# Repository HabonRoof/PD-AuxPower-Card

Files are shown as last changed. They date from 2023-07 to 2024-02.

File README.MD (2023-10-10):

# Type-C PD Auxiliary power supply
### _Light, small, isolated digial power_
Tiny-Aux is a small protable auxiliary digital power supply for electrical engineer using everyday.
As a power electronic engineer, I'm tired moving heavy linear bench power for only less then 1W power.
So I develop this Tiny-Aux for four different voltage as auxiliary power source.
It sould support USB type-C connector and PD protocol fand four different output voltage, but now can only draw 5V input.
Most importantly, it's isolated from primary and secondary, ground path is no more concerned.
## Appearence
Appearence of Tiny-Aux Tiny-Aux side view
The two ER9.5 transformer provide physical isolation side by side.
There are two output channel provide 3.3V/5V and 12V/24V saperately. Use two switches to set the output voltage of each channel.
The black/yellow wire and ground pin is for debugging.
## Features
- PWM limit protection
- UART real-time power monitoring

## Fearures to be develop
- Over current/ Over voltage protection
- FUSB302B driver library
- EEPROM for power event recording

## Specification
- Input voltage: 5V-24V (USB PD is in development)
- Channel 1 output voltage: 3.3V/ 5V
- Channel 1 output current: 1000 mA
- Channel 2 output voltage: 12V/ 24V
- Channel 2 output current: 500 mA
- Total putput wattage: 2W

## Technical detail
All of the component can be placed or soldered by machine automatically, **but no transformer**.
This project using flyback topology as isolated power, so the transformer is the key component and need to satisfy following charactisic.
The bobbin size used is ER9.5, core material is PC44, diameter of conductor is 0.5 mm.
The transformer need grind air-gap manualy. The distant is about 0.5mm. (Need to be confirm).
For **Channel 1** 3.3V/5V rail, the transformer should have this charactisic:
- Primary inductance: 330uH, roughtly 10 turns
- Secondary inductance: 30uH, roughtly 30 turns
 -Leakage inductance: 10uH

For **Channel 2** 12V/24V rail, the transformer should have this charactisic:
- Primary inductance: 30uH, roughtly 3 turns
- Secondary inductance: 330uH, roughtly 30 turns
- Leakage inductance: 10uH

The **dot point** of transformer is marked on PCB schematic file, **DOUBLE CHECK the polarity**.

The switching frequency is set to 200kHz, using voltage control for stable output voltage.
PID parameter can be tune to best for dynamic load.

## Important Notice
The communication pin (UART, Debug interface) is grounded with primary side of Tiny-Aux module, please DO NOT connect to the output channel incase burn your computer.
Over current protection and over voltage protection is not implement yet!
USB PD ptorocol is not implement yet!

## Known Issue
- PD protocol can not read PDO message.
- 5V transient will go into unstable state when applying 100 mA 1000mA dynamic load.
- TPS62177 EN pin connect to GND (fixed in schematic)

## Contribute
If you want to join the development, please feel free to send me e-mail, and I'll send you the hardware for free.

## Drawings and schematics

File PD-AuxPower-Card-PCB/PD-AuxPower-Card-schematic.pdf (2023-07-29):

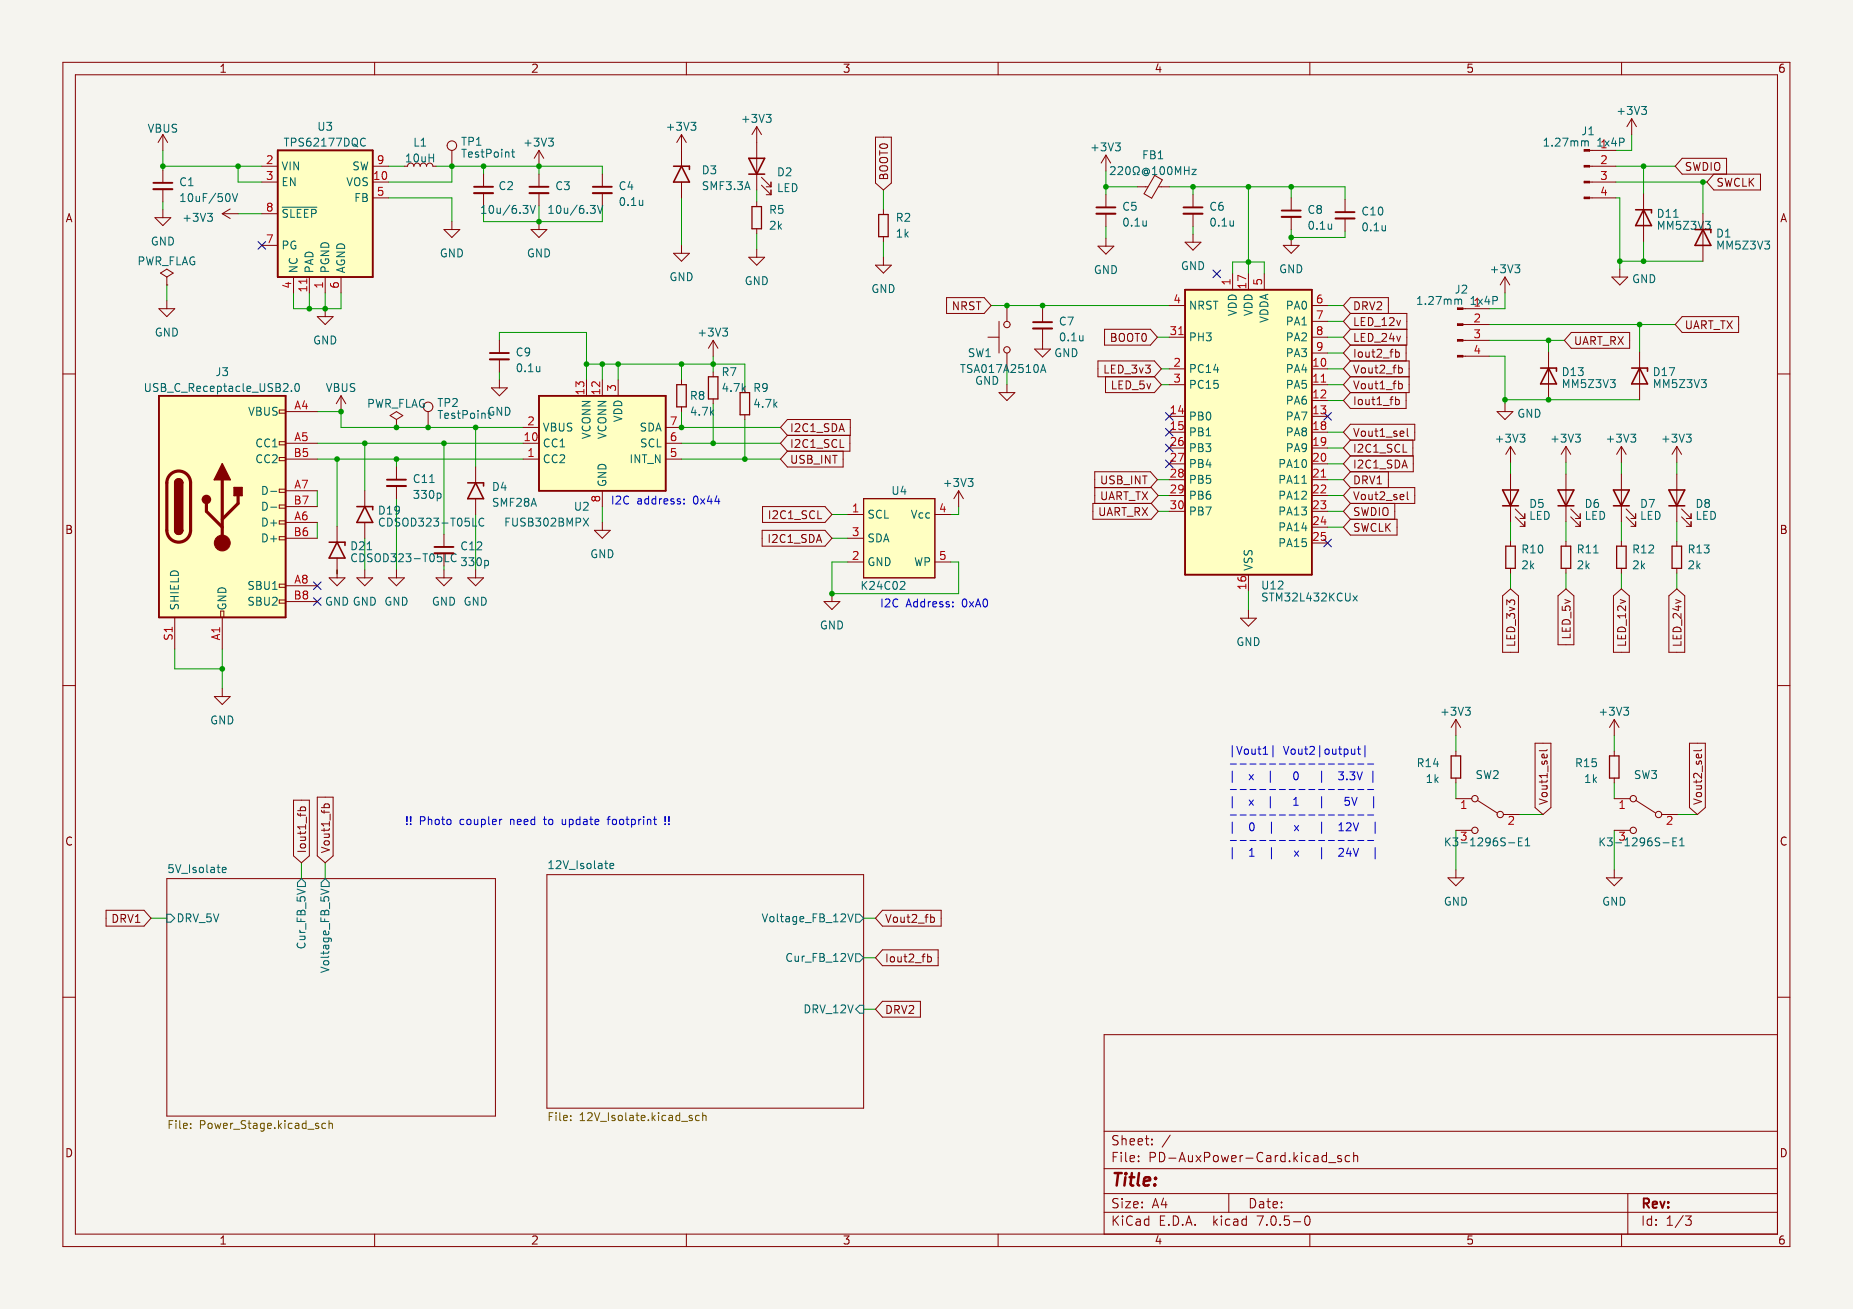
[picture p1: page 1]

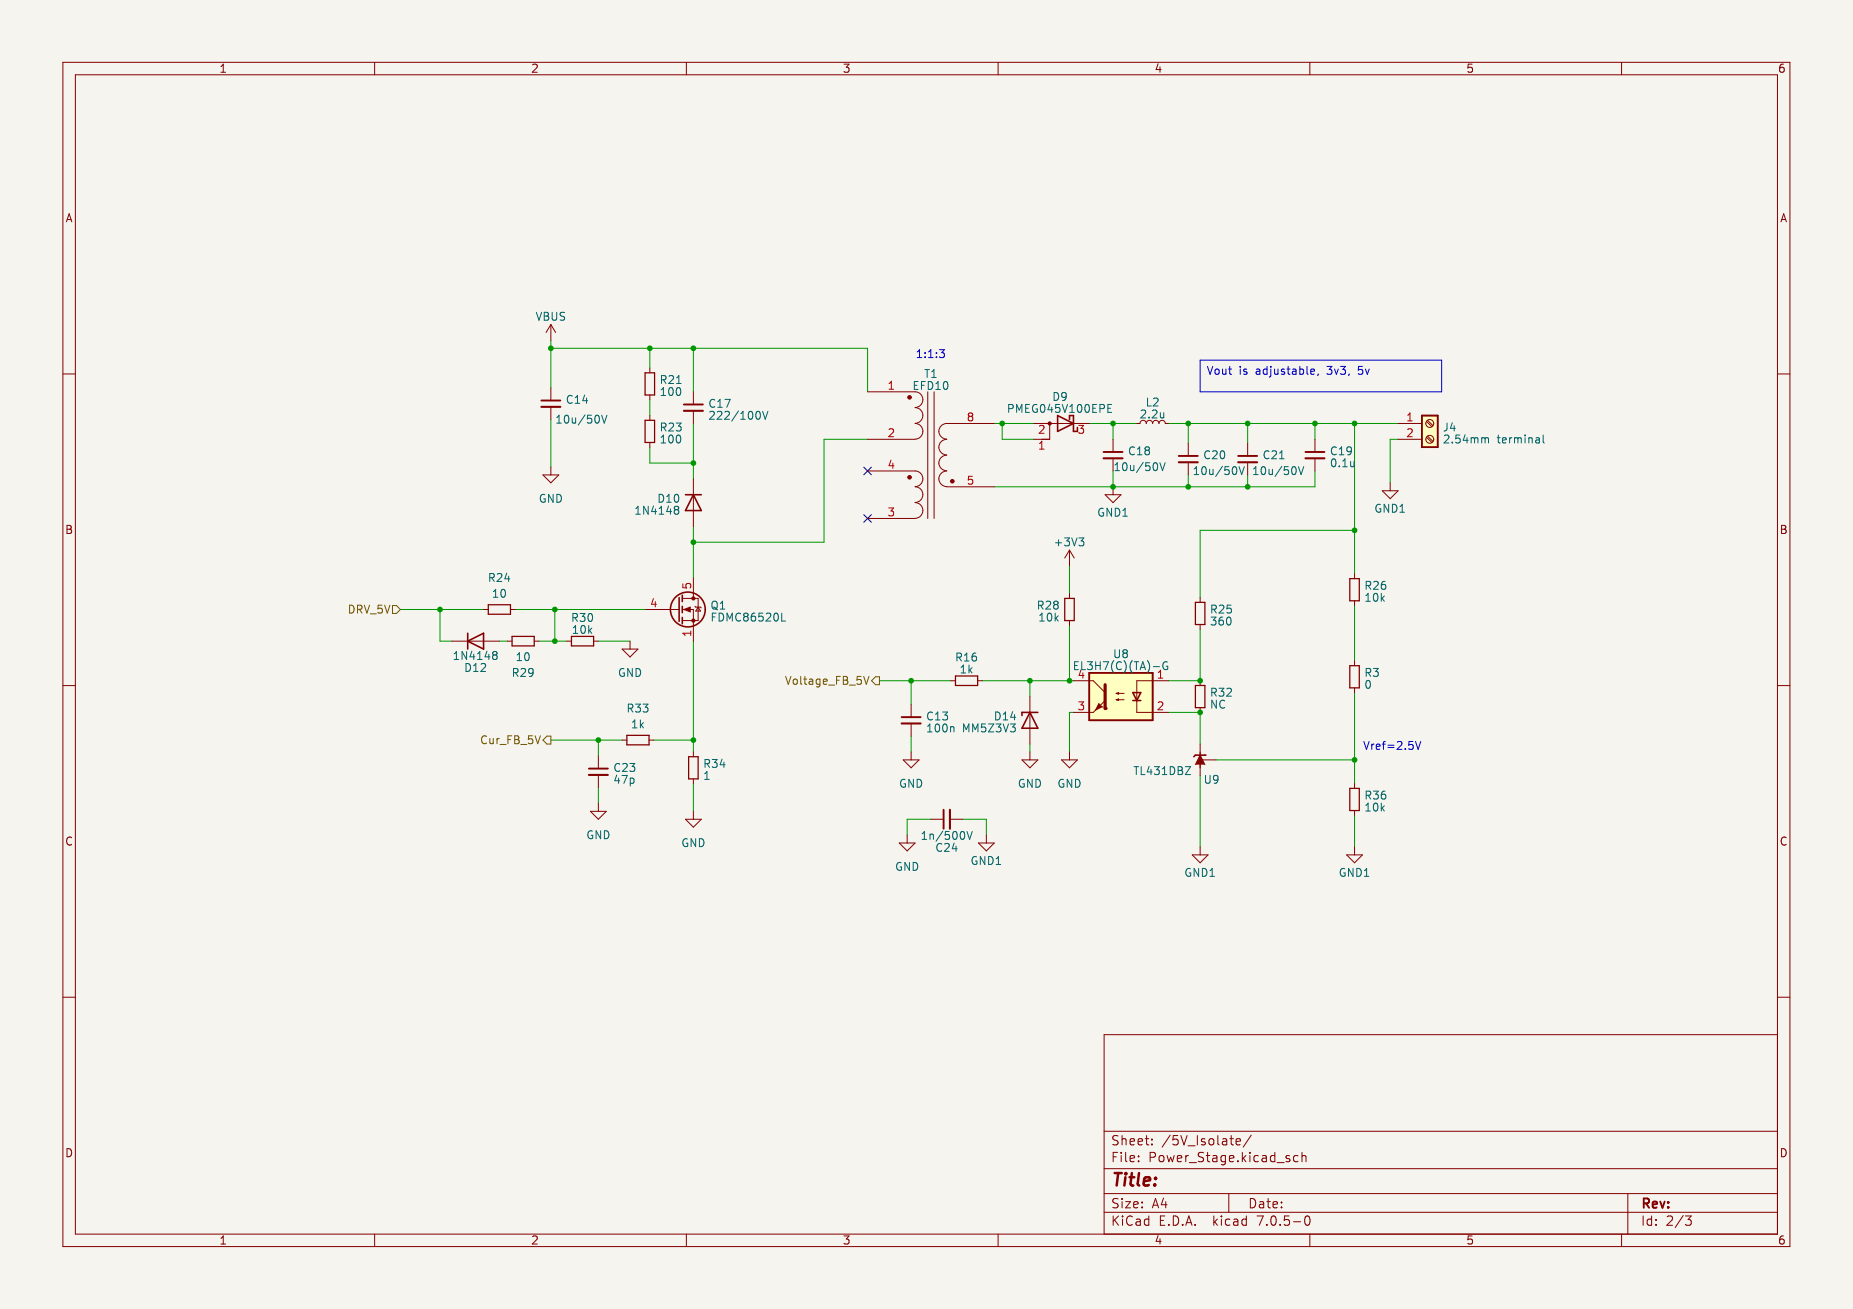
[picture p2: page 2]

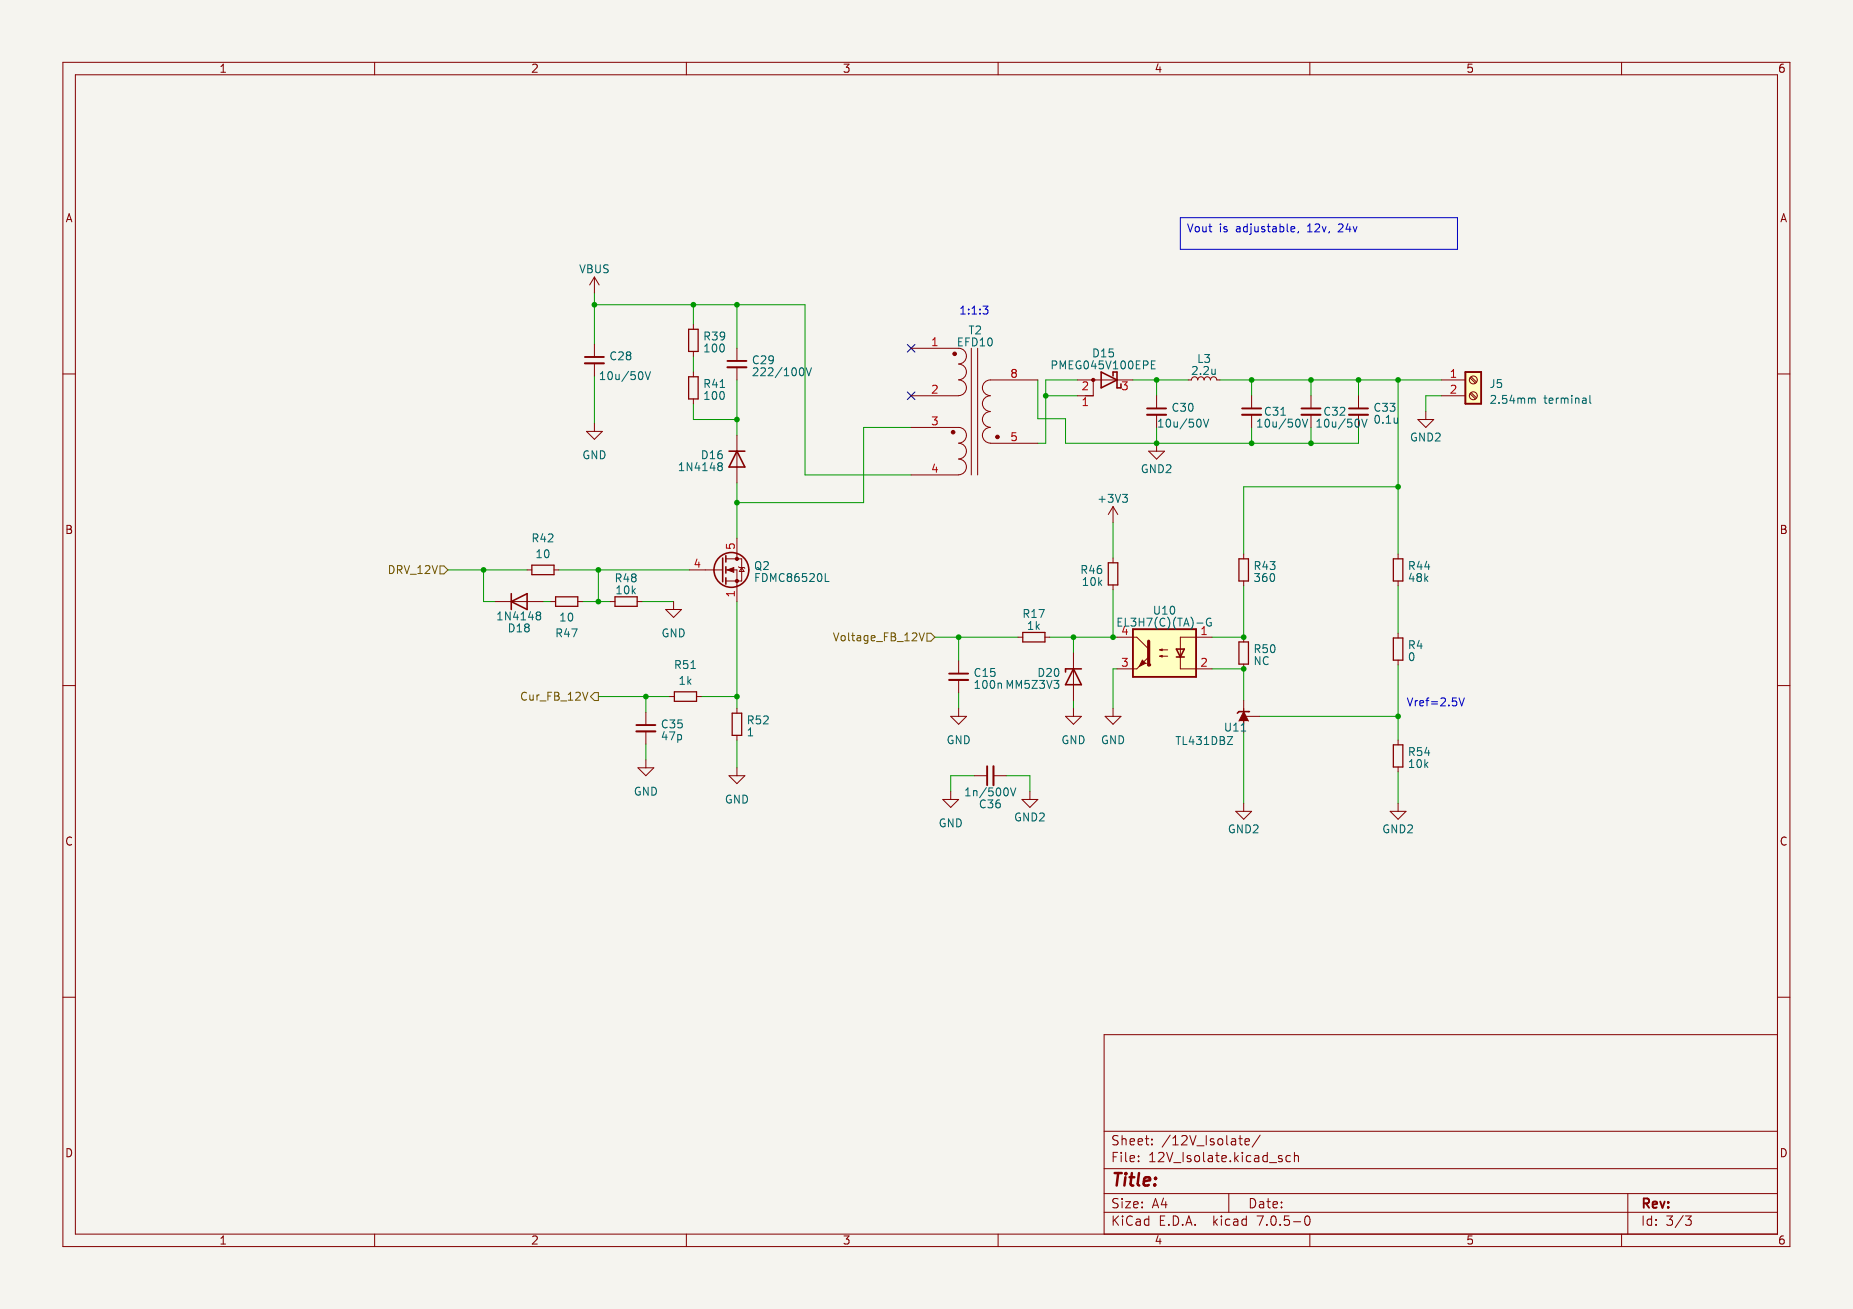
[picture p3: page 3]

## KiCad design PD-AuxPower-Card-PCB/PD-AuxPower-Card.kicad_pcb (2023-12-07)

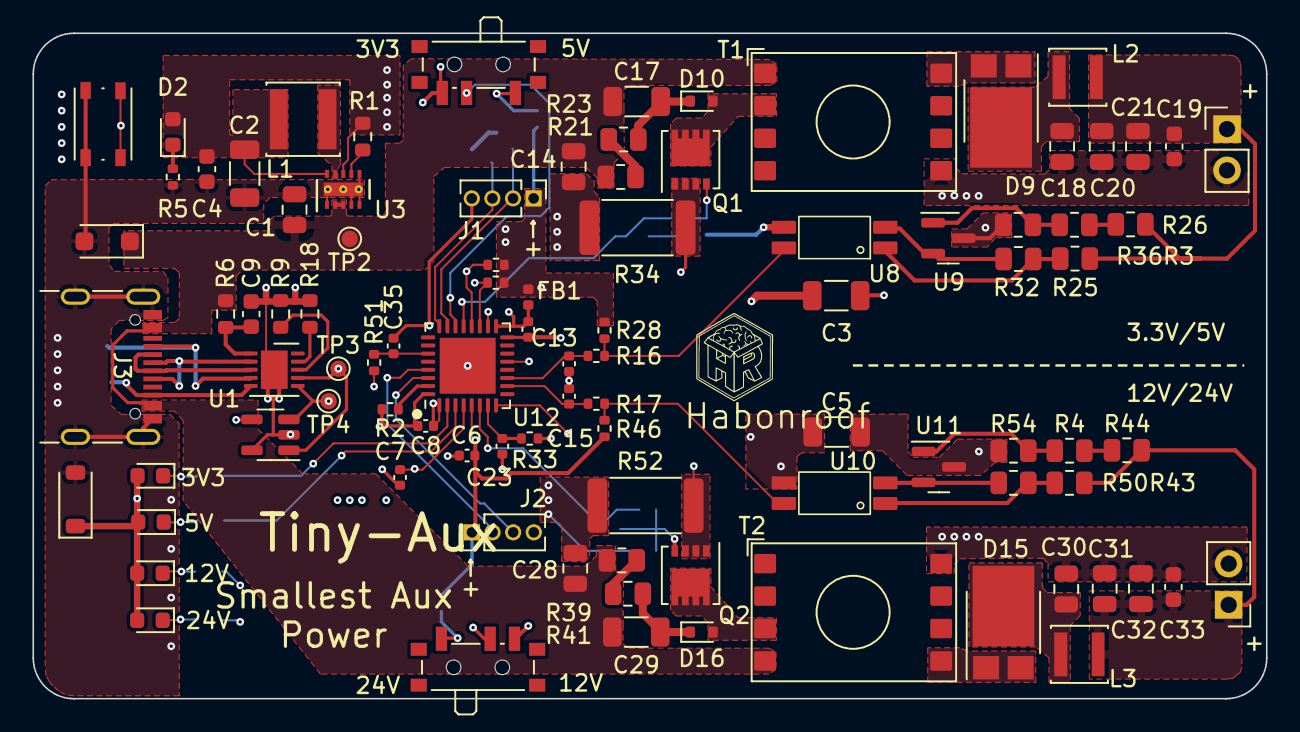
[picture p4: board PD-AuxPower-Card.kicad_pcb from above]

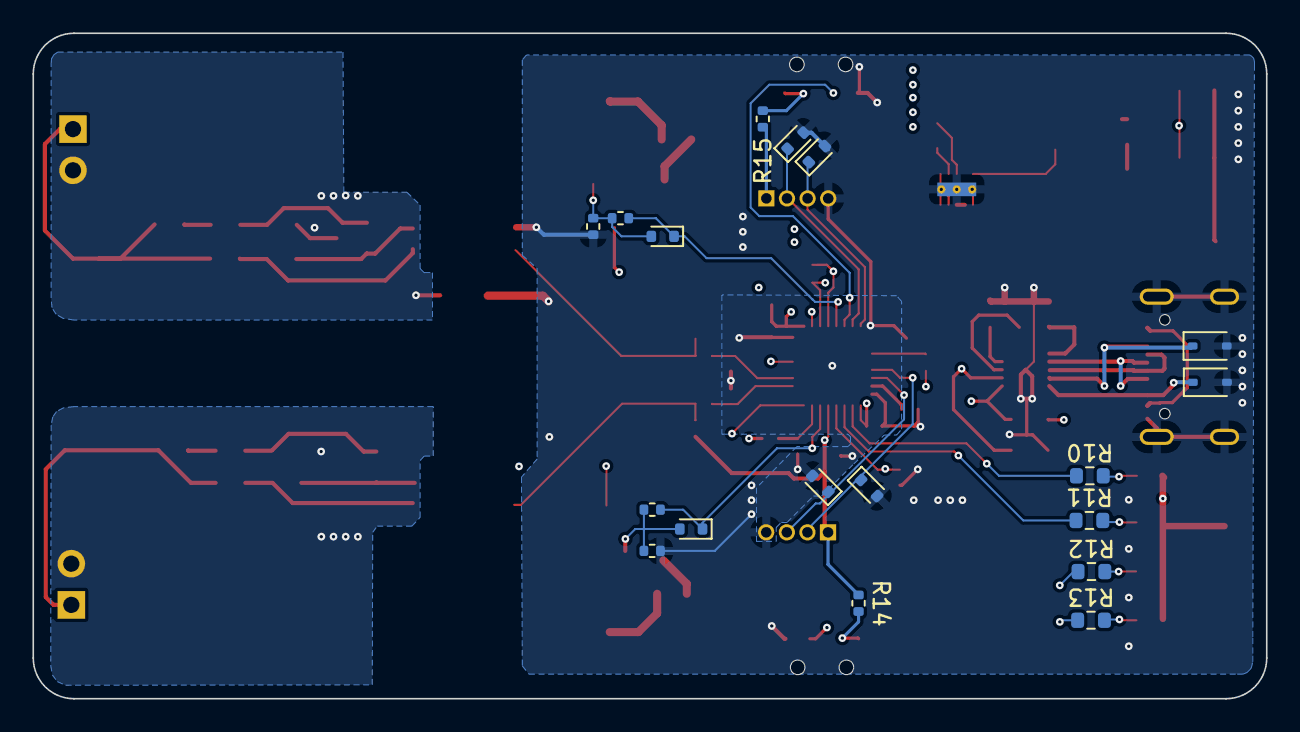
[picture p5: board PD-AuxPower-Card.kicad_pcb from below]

Board: 4 copper layers, 76.0 x 41.0 mm, 112 parts (18 on the bottom side), 68 nets.

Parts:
C1: 2.2u/35V; C_0805_2012Metric
C2: 22u/10V; C_1206_3216Metric
C3, C5: 2200p/500V; C_1206_3216Metric
C4, C19, C33: 0.1u; C_0603_1608Metric
C6, C7, C8, C10: 0.1u; C_0402_1005Metric
C9: 1u; C_0603_1608Metric
C13, C15: 100n; C_0402_1005Metric
C14, C18, C20, C21, C28, C30, C31, C32: 10u/50V; C_0805_2012Metric
C17, C29: 222/100V; C_1206_3216Metric
C23, C35: 47p; C_0402_1005Metric
D1, D11, D13, D17: MM5Z3V3; D_SOD-523
D2, D5, D6, D7, D8: LED; D_0603_1608Metric
D3: SMF3.3A; D_SOD-123
D4: SMF28A; D_SOD-123F
D9, D15: PMEG045V100EPE; Nexperia_CFP15_SOT-1289
D10, D12, D16, D18: 1N4148; D_SOD-523
D19, D21: CDSOD323-T05LC; D_SOD-323
FB1: 220Ω@100MHz; L_0402_1005Metric
J1: SWD; PinHeader_1x04_P1.27mm_Vertical
J2: UART; PinHeader_1x04_P1.27mm_Vertical
J3: USB_C_Receptacle_USB2.0; USB_C_Receptacle_GCT_USB4105-xx-A_16P_TopMnt_Horizontal
J4, J5: 2.54mm terminal; PinHeader_1x02_P2.54mm_Vertical
L1: 10uH; L_Changjiang_FNR4010S
L2, L3: 2.2u; L_Changjiang_FNR3012S
Q1, Q2: FDMC86520L; Diodes_PowerDI3333-8
R1: 100k; R_0603_1608Metric
R2, R5, R14, R15, R30, R48: 10k; R_0402_1005Metric
R3: 8.2k; R_0805_2012Metric
R4, R26: 0; R_0805_2012Metric
R6: 10; R_0603_1608Metric
R7, R8: 4.7k; R_0402_1005Metric
R9, R10, R11, R12, R13, R18: 10k; R_0603_1608Metric
R16, R17, R33, R51: 1k; R_0402_1005Metric
R21, R23, R39, R41: 100; R_0805_2012Metric
R24, R42: 10; R_0402_1005Metric
R25: 1k; R_0805_2012Metric
R28, R46: 50; R_0402_1005Metric
R32, R50: NC; R_0805_2012Metric
R34, R52: 1; R_2512_6332Metric
R36, R54: 10k; R_0805_2012Metric
R43: 6.8k; R_0805_2012Metric
R44: 33k; R_0805_2012Metric
SW1: TSA017A2510A; SW_Push_1P1T_NO_Vertical_Wuerth_434133025816
SW2, SW3: K3-1296S-E1; SW_SPDT_PCM12
T1, T2: ER 9.5; Transformer_ER9.5_11.6mmx8.2mm
TP2: VIN; TestPoint_Pad_D1.0mm
TP3: SCL; TestPoint_Pad_D1.0mm
TP4: SDA; TestPoint_Pad_D1.0mm
U1: HUSB328_DD2; DFN-10-1EP_3x3mm_P0.5mm_EP1.65x2.38mm
U3: TPS62177DQC; WSON-10-1EP_2x3mm_P0.5mm_EP0.84x2.4mm_ThermalVias
U4: K24C02; SOT-23-5
U8, U10: LTV-217; SOP-4-175mil
U9: TLV431BFTA; SOT-23
U11: TL431DBZ; SOT-23
U12: STM32L432KCUx; QFN-32-1EP_5x5mm_P0.5mm_EP3.45x3.45mm

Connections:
+3V3: C2.1, C4.1, C6.1, D2.2 (A), D3.1 (A1), D5.2 (A), D6.2 (A), D7.2 (A), D8.2 (A), FB1.2, J1.1, J2.1, L1.2, R1.2, R7.1, R8.1, R14.1, R15.1, R28.1, R46.1, U3.8 (~SLEEP), U3.10 (VOS), U4.4 (Vcc), U12.5 (VDDA)
BOOT0: R2.1, U12.31 (PH3)
DRV1: D12.1 (K), R24.2, U12.21 (PA11)
DRV2: D18.1 (K), R42.2, U12.6 (PA0)
GND: C1.2, C2.2, C3.1, C4.2, C5.1, C6.2, C7.2, C8.2, C9.2, C10.2, C13.2, C14.2, C15.2, C23.2, C28.2, C35.2, D1.2 (A), D3.2 (A2), D4.2 (A2), D11.2 (A), D13.2 (A), D17.2 (A), D19.2 (A2), D21.2 (A2), J1.4, J2.4, J3.A1 (GND), J3.A12 (GND), J3.B1 (GND), J3.B12 (GND), J3.S1 (SHIELD), R2.2, R5.2, R9.2, R18.2, R30.1, R34.2, R48.1, R52.2, SW1.1, SW2.3 (C), SW3.3 (C), U1.11 (GND), U3.1 (PGND), U3.4 (NC), U3.5 (FB), U3.6 (AGND), U3.11 (PAD), U4.2 (GND), U4.5 (WP), U8.3, U10.3, U12.16 (VSS), U12.32 (VSS), U12.33 (VSS)
GND1: C3.2, C18.2, C19.2, C20.2, C21.2, J4.2, R36.1, T1.5 (AB), U9.3 (A)
GND2: C5.2, C30.2, C31.2, C32.2, C33.2, J5.2, R54.1, T2.8 (AA), U11.3 (A)
I2C1_SCL: R8.2, TP3.1, U1.7 (SCL), U4.1 (SCL), U12.19 (PA9)
I2C1_SDA: R7.2, TP4.1, U1.6 (SDA), U4.3 (SDA), U12.20 (PA10)
Iout1_fb: C23.1, R33.1, U12.7 (PA1)
Iout2_fb: C35.1, R51.1, U12.27 (PB4)
LED_3v3: R10.1, U12.2 (PC14)
LED_5v: R11.1, U12.3 (PC15)
LED_12v: R12.1, U12.13 (PA7)
LED_24v: R13.1, U12.8 (PA2)
NRST: C7.1, SW1.2, U12.4 (NRST)
unnamed: C8.1, C10.1, FB1.1, U12.1 (VDD), U12.17 (VDD)
unnamed: D2.1 (K), R5.1
unnamed: D5.1 (K), R10.2
unnamed: D6.1 (K), R11.2
unnamed: D7.1 (K), R12.2
unnamed: D8.1 (K), R13.2
unnamed: C18.1, D9.3 (K), L2.1
unnamed: D10.2 (A), Q1.5 (D), T1.2 (SB)
unnamed: C17.2, D10.1 (K), R23.1
unnamed: D12.2 (A), Q1.4 (G), R24.1, R30.2
unnamed: C30.1, D15.3 (K), L3.1
unnamed: D16.2 (A), Q2.5 (D), T2.3 (SC)
unnamed: C29.2, D16.1 (K), R41.1
unnamed: D18.2 (A), Q2.4 (G), R42.1, R48.2
unnamed: D19.1 (A1), J3.A5 (CC1), U1.4 (CC1)
unnamed: D21.1 (A1), J3.B5 (CC2), U1.5 (CC2)
unnamed: C19.1, C20.1, C21.1, J4.1, L2.2, R25.2, R26.2
unnamed: C31.1, C32.1, C33.1, J5.1, L3.2, R43.2, R44.2
unnamed: Q1.1 (S), R33.2, R34.1
unnamed: Q2.1 (S), R51.2, R52.1
unnamed: R4.2, R44.1
unnamed: R16.2, R28.2, U8.4
unnamed: R17.2, R46.2, U10.4
unnamed: R21.1, R23.2
unnamed: R25.1, R32.2, U8.1
unnamed: R3.2, R26.1
unnamed: R39.1, R41.2
unnamed: R43.1, R50.2, U10.1
unnamed: R14.2, SW2.1 (A)
unnamed: R15.2, SW3.1 (A)
unnamed: D9.1 (A), D9.2 (A), T1.8 (AA)
unnamed: D15.1 (A), D15.2 (A), T2.5 (AB)
unnamed: J3.A6 (D+), J3.B6 (D+), U1.2 (D+)
unnamed: J3.A7 (D-), J3.B7 (D-), U1.3 (D-)
unnamed: R18.1, U1.9 (ISET)
unnamed: C9.1, R6.2, U1.1 (VIN)
unnamed: R9.1, U1.8 (VSET)
unnamed: R1.1, U3.7 (PG)
unnamed: L1.1, U3.9 (SW)
unnamed: R32.1, U8.2, U9.2 (K)
unnamed: R3.1, R36.2, U9.1 (REF)
unnamed: R50.1, U10.2, U11.2 (K)
unnamed: R4.1, R54.2, U11.1 (REF)
SWCLK: D1.1 (K), J1.3, U12.24 (PA14)
SWDIO: D11.1 (K), J1.2, U12.23 (PA13)
UART_RX: D13.1 (K), J2.3, U12.30 (PB7)
UART_TX: D17.1 (K), J2.2, U12.29 (PB6)
VBUS: C1.1, C14.1, C17.1, C28.1, C29.1, D4.1 (A1), J3.A4 (VBUS), J3.A9 (VBUS), J3.B4 (VBUS), J3.B9 (VBUS), R6.1, R21.2, R39.2, T1.1 (SA), T2.4 (SD), TP2.1, U3.2 (VIN), U3.3 (EN)
Vout1_fb: C13.1, R16.1, U12.11 (PA5)
Vout1_sel: SW2.2 (B), U12.18 (PA8)
Vout2_fb: C15.1, R17.1, U12.10 (PA4)
Vout2_sel: SW3.2 (B), U12.22 (PA12)

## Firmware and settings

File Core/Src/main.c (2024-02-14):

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
/* Includes ------------------------------------------------------------------*/
#include "main.h"

/* USER CODE BEGIN Includes */
#include "stdio.h"
#include "string.h"
#include "pd_aux_typedef.h"
#include "pid.h"
#include "FUSB302B_driver.h"
#include "pd_sink.h"
/* USER CODE END Includes */

ADC_HandleTypeDef hadc1;
DMA_HandleTypeDef hdma_adc1;

COMP_HandleTypeDef hcomp1;
COMP_HandleTypeDef hcomp2;

DAC_HandleTypeDef hdac1;

I2C_HandleTypeDef hi2c1;

TIM_HandleTypeDef htim1;
TIM_HandleTypeDef htim2;
TIM_HandleTypeDef htim15;
TIM_HandleTypeDef htim16;

UART_HandleTypeDef huart1;

void SystemClock_Config(void);
static void MX_GPIO_Init(void);
static void MX_DMA_Init(void);
static void MX_ADC1_Init(void);
static void MX_TIM1_Init(void);
static void MX_I2C1_Init(void);
static void MX_TIM2_Init(void);
static void MX_USART1_UART_Init(void);
static void MX_TIM16_Init(void);
static void MX_TIM15_Init(void);
static void MX_COMP1_Init(void);
static void MX_COMP2_Init(void);
static void MX_DAC1_Init(void);
/* USER CODE BEGIN 0 */
uint16_t ADC_res[2] = {0};
uint16_t Iout1_FB = 0;
uint16_t Iout2_FB = 0;
uint16_t Vout1_FB = 0;
uint16_t Vout2_FB = 0;
uint32_t timer15_ctr = 0;
uint32_t timer16_ctr = 0;
uint16_t adc_isr_ctr = 0;
uint16_t pwm1_duty = PWM1_MIN_DUTY;
uint16_t pwm2_duty = PWM2_MIN_DUTY;
uint8_t SW_3v3_5v = 0;
uint8_t SW_12v_24v = 0;
uint8_t SW_3v3_5v_old = 2;
uint8_t SW_12v_24v_old = 2;


// FUSB302B PD controller I2C address
HAL_StatusTypeDef i2c_status;

// UART communication variables
char uart_tx_msg[256];

// PID parameter structure
extern PID_struct_t Vout1_pid_param;
extern PID_struct_t Vout2_pid_param;

// FUSB302B object definition
extern FUSB302B_t fusb;

// variables for monitor board status
Board_status_t board_status;

/* USER CODE END 0 */

/**
  * @brief  The application entry point.
  * @retval int
  */
int main(void)
{
  /* MCU Configuration--------------------------------------------------------*/

  /* Reset of all peripherals, Initializes the Flash interface and the Systick. */
  HAL_Init();

  /* Configure the system clock */
  SystemClock_Config();

  /* USER CODE BEGIN SysInit */

  // Enable SysTick timer (if not enabled by default)
//  HAL_SYSTICK_Config(HAL_RCC_GetHCLKFreq());
  /* USER CODE END SysInit */

  /* Initialize all configured peripherals */
  MX_GPIO_Init();
  MX_DMA_Init();
  MX_ADC1_Init();
  MX_TIM1_Init();
  MX_I2C1_Init();
  MX_TIM2_Init();
  MX_USART1_UART_Init();
  MX_TIM16_Init();
  MX_TIM15_Init();
  MX_COMP1_Init();
  MX_COMP2_Init();
  MX_DAC1_Init();
  /* USER CODE BEGIN 2 */
  // Initialize FUSB302B PD chip
  //
  Init_pid(&Vout1_pid_param);
  Init_pid(&Vout2_pid_param);

  // ADC calibration
  HAL_ADCEx_Calibration_Start(&hadc1, ADC_SINGLE_ENDED);
  HAL_Delay(1);

  // start pwm generation
  HAL_TIM_PWM_Start_IT(&htim1, TIM_CHANNEL_4);
  HAL_TIM_PWM_Start_IT(&htim2, TIM_CHANNEL_1);

  // kick off ADC DMA conversion, this function active ADC peripheral
  HAL_ADC_Start_DMA(&hadc1, (uint32_t*)&ADC_res, 2);

  // start 10Hz house-keeping timer
  HAL_TIM_Base_Start_IT(&htim16);

  // start 10kHz general timer for ADC DMA software trigger
  HAL_TIM_Base_Start_IT(&htim15);

  // initial FUSB302B PD chip
  FUSB302B_init(&hi2c1, &fusb);
  FUSB302B_read_all(&hi2c1, &fusb);

  /* USER CODE END 2 */

  /* Infinite loop */
  /* USER CODE BEGIN WHILE */
  while (1)
  {
//	  i2c_status = HAL_I2C_Master_Transmit(&hi2c1, FUSB302B_ADDR, i2c_buffer, 1, HAL_MAX_DELAY);
//	  if(i2c_status == HAL_OK){
//		  i2c_status = HAL_I2C_Master_Receive(&hi2c1, FUSB302B_ADDR, i2c_buffer, 1, HAL_MAX_DELAY);
//	  	  if(i2c_status == HAL_OK){
//	  		i2c_data =  i2c_buffer[0];
//	  	  }
//	  	  else{
//			  board_status = I2C_ERROR;
//	  	  }
//	  }
//	  else{
//		  board_status = I2C_ERROR;
//	  }
//	  sprintf(uart_tx_msg,"Iout1_FB = %d Iout2_FB = %d Vout1_FB = %d Vout2_FB = %d \n\r",Iout1_FB, Iout2_FB, Vout1_FB, Vout2_FB);
//	  HAL_UART_Transmit(&huart1, (uint8_t*)uart_tx_msg, strlen(uart_tx_msg), 10);

    /* USER CODE END WHILE */

    /* USER CODE BEGIN 3 */
	  HAL_Delay(500);

  }
  /* USER CODE END 3 */
}

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
/* USER CODE BEGIN 4 */
void HAL_ADC_ConvCpltCallback(ADC_HandleTypeDef* hadc){
	// 65kHz update rate
	adc_isr_ctr = 0;
	// Read The ADC Conversion result to variables
	Vout2_FB = ADC_res[0];	// PA4
	Vout1_FB = ADC_res[1];	// PA5

	Vout1_pid_param.adc_fb_value = Vout1_FB;
	pid_process(&Vout1_pid_param);
	htim1.Instance->CCR4 = Vout1_pid_param.output;

	Vout2_pid_param.adc_fb_value = Vout2_FB;
	pid_process(&Vout2_pid_param);
	htim2.Instance->CCR1 = Vout2_pid_param.output;
}

void HAL_TIM_PeriodElapsedCallback(TIM_HandleTypeDef *htim){
	if(htim == &htim16){
		SW_3v3_5v  = HAL_GPIO_ReadPin(Vout1_sel_GPIO_Port, Vout1_sel_Pin);
		SW_12v_24v = HAL_GPIO_ReadPin(Vout2_sel_GPIO_Port, Vout2_sel_Pin);

		if(SW_3v3_5v != SW_3v3_5v_old){
			SW_3v3_5v_old = SW_3v3_5v;
			// indicate current output voltage mode
			if(SW_3v3_5v == 1){
				_3v3LED_OFF;
				_5vLED_ON;
				Vout1_pid_param.target_value = _5v_ADC_target;
//				sprintf(uart_tx_msg,"Output1 set to 3v3\n\r");
			}
			else{
				_3v3LED_ON;
				_5vLED_OFF;
				Vout1_pid_param.target_value = _3v3_ADC_target;
//				sprintf(uart_tx_msg,"Output1 set to 5v\n\r");
			}
//			HAL_UART_Transmit(&huart1, (uint8_t*)uart_tx_msg, strlen(uart_tx_msg), 10);
		}

		if(SW_12v_24v != SW_12v_24v_old){
			SW_12v_24v_old = SW_12v_24v;
			if(SW_12v_24v == 1){
				_12vLED_OFF;
				_24vLED_ON;
				Vout2_pid_param.target_value = _24v_ADC_target;
//				sprintf(uart_tx_msg,"Output2 set to 12v\n\r");
			}
			else{

				_12vLED_ON;
				_24vLED_OFF;
				Vout2_pid_param.target_value = _12v_ADC_target;
//				sprintf(uart_tx_msg,"Output2 set to 24v\n\r");
			}
//			HAL_UART_Transmit(&huart1, (uint8_t*)uart_tx_msg, strlen(uart_tx_msg), 10);
		}
		// 100Hz counter
		timer16_ctr ++;
	}
}

/* USER CODE END 4 */
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


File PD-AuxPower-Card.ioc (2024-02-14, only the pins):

Mcu.UserName=STM32L432KCUx
PA0.GPIO_Label=DRV2
PA0.Signal=S_TIM2_CH1
PA1.Signal=COMP1_INP
PA10.Signal=I2C1_SDA
PA11.GPIO_Label=DRV1
PA11.Signal=S_TIM1_CH4
PA12.GPIO_Label=Vout1_sel
PA12.Signal=GPIO_Input
PA2.GPIO_Label=LED_24v
PA2.Signal=GPIO_Output
PA4.GPIO_Label=Vout2_FB
PA4.Signal=ADCx_IN9
PA5.GPIO_Label=Vout1_FB
PA5.Signal=ADCx_IN10
PA7.GPIO_Label=LED_12v
PA7.Signal=GPIO_Output
PA8.GPIO_Label=Vout2_sel
PA8.Signal=GPIO_Input
PA9.Signal=I2C1_SCL
PB6.Signal=USART1_TX
PB7.Signal=USART1_RX

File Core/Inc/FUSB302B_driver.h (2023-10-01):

/*
 *	FUSB302B_driver.h
 *
 *  Created on: Aug 19, 2023
 *  Author: Habonroof<johnson35762@gmail.com>
 *  Reference author: Philip Tschiemer
 */


#ifndef INC_FUSB302B_DRIVER_H_
#define INC_FUSB302B_DRIVER_H_
#include "stdint.h"
#include "stm32l4xx_hal.h"
#include "string.h"

//*********************************************
// Register address of FUSB302B PD controller
//*********************************************
#define FUSB302B_DeviceID_Version_MASK			0xF0
#define FUSB302B_DeviceID_Revision_MASK			0x0F

#define FUSB302B_Switches0_PU_EN_MASK			0b11000000
#define FUSB302B_Switches0_PU_EN2				0b10000000
#define FUSB302B_Switches0_PU_EN1				0b01000000
#define FUSB302B_Switches0_VCONN_CC_MASK		0b00110000
#define FUSB302B_Switches0_VCONN_CC2			0b00100000
#define FUSB302B_Switches0_VCONN_CC1			0b00010000
#define FUSB302B_Switches0_MEAS_CC_MASK			0b00001100
#define FUSB302B_Switches0_MEAS_CC2				0b00001000
#define FUSB302B_Switches0_MEAS_CC1				0b00000100
#define FUSB302B_Switches0_PDWN_MASK			0b00000011
#define FUSB302B_Switches0_PDWN2				0b00000010
#define FUSB302B_Switches0_PDWN1				0b00000001

#define FUSB302B_Switches1_POWERROLE			0b10000000
#define FUSB302B_Switches1_SPECREV_MASK			0b01100000
#define FUSB302B_Switches1_DATAROLE				0b00010000
#define FUSB302B_Switches1_Reserved				0b00001000
#define FUSB302B_Switches1_AUTO_CRC				0b00000100
#define FUSB302B_Switches1_TXCC_MASK			0b00000011

#define FUSB302B_Switches1_SPECREV_Rev1_0		0b00000000
#define FUSB302B_Switches1_SPECREV_Rev2_0		0b00100000
#define FUSB302B_Switches1_POWERROLE_Source		0b10000000
#define FUSB302B_Switches1_POWERROLE_Sink		0b00000000
#define FUSB302B_Switches1_DATAROLE_Source		0b00010000
#define FUSB302B_Switches1_DATAROLE_Sink		0b00000000
#define FUSB302B_Switches1_TXCC2				0b00000010
#define FUSB302B_Switches1_TXCC1				0b00000001

#define FUSB302B_Measure_Reserved				0b10000000
#define FUSB302B_Measure_MEAS_VBUS				0b01000000
#define FUSB302B_Measure_MDAC_MASK				0b00111111

#define FUSB302B_Slice_SDAC_HYS_MASK			0b11000000
#define FUSB302B_Slice_SDAC_MASK				0b00111111

#define FUSB302B_Control0_Reserved_MASK			0b10010000
#define FUSB302B_Control0_TX_FLUSH				0b01000000
#define FUSB302B_Control0_INT_MASK				0b00100000
#define FUSB302B_Control0_HOST_CUR_MASK			0b00001100
#define FUSB302B_Control0_AUTO_PRE				0b00000010
#define FUSB302B_Control0_TX_START				0b00000001

#define FUSB302B_Control0_HOST_CUR_NoCurrent			0b00000000
#define FUSB302B_Control0_HOST_CUR_DefaultUSBPower		0b00000100
#define FUSB302B_Control0_HOST_CUR_MediumCurrentMode	0b00001000
#define FUSB302B_Control0_HOST_CUR_HighCurrentMode		0b00001100

#define FUSB302B_Control1_Reserved_MASK			0b10001000
#define FUSB302B_Control1_ENSOP2DB				0b01000000
#define FUSB302B_Control1_ENSOP1DB				0b00100000
#define FUSB302B_Control1_BIST_MODE2			0b00010000
#define FUSB302B_Control1_RX_FLUSH				0b00000100
#define FUSB302B_Control1_ENSOP2				0b00000010
#define FUSB302B_Control1_ENSOP1				0b00000001

#define FUSB302B_Control2_Reserved_MASK			0b00010000
#define FUSB302B_Control2_TOG_SAVE_MASK			0b11000000
#define FUSB302B_Control2_TOG_DR_ONLY			0b00100000
#define FUSB302B_Control2_WAKE_EN				0b00001000
#define FUSB302B_Control2_MODE_MASK				0b00000110
#define FUSB302B_Control2_TOGGLE				0b00000001

#define FUSB302B_Control2_MODE_SrcPolling		0b00000110
#define FUSB302B_Control2_MODE_SnkPolling		0b00000100
#define FUSB302B_Control2_MODE_DrpPolling		0b00000010
#define FUSB302B_Control2_MODE_Off				0b00000000

#define FUSB302B_Control3_Reserved_MASK			0b10100000
#define FUSB302B_Control3_SEND_HARD_RESET		0b01000000
#define FUSB302B_Control3_AUTO_HARDRESET		0b00010000
#define FUSB302B_Control3_AUTO_SOFTRESET		0b00001000
#define FUSB302B_Control3_N_RETRIES_MASK		0b00000110
#define FUSB302B_Control3_AUTO_RETRY			0b00000001

#define FUSB302B_Mask1_M_VBUSOK					0b10000000
#define FUSB302B_Mask1_M_ACTIVITY				0b01000000
#define FUSB302B_Mask1_M_COMP_CHNG				0b00100000
#define FUSB302B_Mask1_M_CRC_CHK				0b00010000
#define FUSB302B_Mask1_M_ALERT					0b00001000
#define FUSB302B_Mask1_M_WAKE					0b00000100
#define FUSB302B_Mask1_M_COLLISION				0b00000010
#define FUSB302B_Mask1_M_BC_LVL					0b00000001

#define FUSB302B_Mask1_ALL						0xFF

#define FUSB302B_Power_Reserved_MASK			0b11110000
#define FUSB302B_Power_PWR_MASK					0b00001111

#define FUSB302B_Power_PWR_InternalOscillator 	0b00001000
#define FUSB302B_Power_PWR_MeasurementBlock		0b00000100
#define FUSB302B_Power_PWR_RxAndCur4MB			0b00000010
#define FUSB302B_Power_PWR_BandgapAndWake		0b00000001

#define FUSB302B_Reset_Reserved_MASK			0b11111100
#define FUSB302B_Reset_PD_RESET					0b00000010
#define FUSB302B_Reset_SW_RES					0b00000001

#define FUSB302B_OCPreg_Reserved_MASK			0b11110000
#define FUSB302B_OCPreg_OCP_RANGE				0b00001000
#define FUSB302B_OCPreg_OCP_CUR_MASK			0b00000111

#define FUSB302B_Maska_M_OCP_TEMP				0b10000000
#define FUSB302B_Maska_M_TOGDONE				0b01000000
#define FUSB302B_Maska_M_SOFTFAIL				0b00100000
#define FUSB302B_Maska_M_RETRYFAIL				0b00010000
#define FUSB302B_Maska_M_HARDSENT				0b00001000
#define FUSB302B_Maska_M_TXSENT					0b00000100
#define FUSB302B_Maska_M_SOFTRST				0b00000010
#define FUSB302B_Maska_M_HARDRST				0b00000001

#define FUSB302B_Maska_ALL						0xFF

#define FUSB302B_Maskb_Reserved_MASK			0b11111110
#define FUSB302B_Maskb_M_GCRCSENT				0b00000001

#define FUSB302B_Maskb_ALL						0b00000001

#define FUSB302B_Control4_Reserved_MASK			0b11111110
#define FUSB302B_Control4_TOG_USRC_EXIT			0b00000001

#define FUSB302B_Status0a_Reserved_MASK			0b11000000
#define FUSB302B_Status0a_SOFTFAIL				0b00100000
#define FUSB302B_Status0a_RETRYFAIL				0b00010000
#define FUSB302B_Status0a_POWER_MASK			0b00001100
#define FUSB302B_Status0a_SOFTRST				0b00000010
#define FUSB302B_Status0a_HARDRST				0b00000001

#define FUSB302B_Status1a_Reserved_MASK			0b11000000
#define FUSB302B_Status1a_TOGSS					0b00111000
#define FUSB302B_Status1a_RXSOP2DB				0b00000100
#define FUSB302B_Status1a_RXSOP1DB				0b00000010
#define FUSB302B_Status1a_RXSOP					0b00000001

#define FUSB302B_Status1a_TOGSS_Running			0b00000000
#define FUSB302B_Status1a_TOGSS_SRC_on_CC1		0b00001000
#define FUSB302B_Status1a_TOGSS_SRC_on_CC2		0b00010000
#define FUSB302B_Status1a_TOGSS_SNK_on_CC1		0b00101000
#define FUSB302B_Status1a_TOGSS_SNK_on_CC2		0b00110000
#define FUSB302B_Status1a_TOGSS_AudioAccessory 	0b00111000

#define FUSB302B_Interrupta_I_OCP_TEMP			0b10000000
#define FUSB302B_Interrupta_I_TOGDONE			0b01000000
#define FUSB302B_Interrupta_I_SOFTFAIL			0b00100000
#define FUSB302B_Interrupta_I_RETRYFAIL			0b00010000
#define FUSB302B_Interrupta_I_HARDSENT			0b00001000
#define FUSB302B_Interrupta_I_TXSENT			0b00000100
#define FUSB302B_Interrupta_I_SOFTRST			0b00000010
#define FUSB302B_Interrupta_I_HARDRST			0b00000001

#define FUSB302B_Interrupta_I_ALL				0xFF

#define FUSB302B_Interruptb_Reserved_MASK		0b11111110
#define FUSB302B_Interruptb_I_GCRCSENT			0b00000001
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

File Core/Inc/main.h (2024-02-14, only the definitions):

#define LED_3v3_Pin GPIO_PIN_14
#define LED_3v3_GPIO_Port GPIOC
#define LED_5v_Pin GPIO_PIN_15
#define LED_5v_GPIO_Port GPIOC
#define DRV2_Pin GPIO_PIN_0
#define DRV2_GPIO_Port GPIOA
#define LED_24v_Pin GPIO_PIN_2
#define LED_24v_GPIO_Port GPIOA
#define Vout2_FB_Pin GPIO_PIN_4
#define Vout2_FB_GPIO_Port GPIOA
#define Vout1_FB_Pin GPIO_PIN_5
#define Vout1_FB_GPIO_Port GPIOA
#define LED_12v_Pin GPIO_PIN_7
#define LED_12v_GPIO_Port GPIOA
#define Vout2_sel_Pin GPIO_PIN_8
#define Vout2_sel_GPIO_Port GPIOA
#define DRV1_Pin GPIO_PIN_11
#define DRV1_GPIO_Port GPIOA
#define Vout1_sel_Pin GPIO_PIN_12
#define Vout1_sel_GPIO_Port GPIOA
#define SWDIO_Pin GPIO_PIN_13
#define SWDIO_GPIO_Port GPIOA
#define SWCLK_Pin GPIO_PIN_14
#define SWCLK_GPIO_Port GPIOA

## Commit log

2023-07-13 ADD: First commit for PD auxiliary power project.
    [12V_Isolate.kicad_sch, PD-AuxPower-Card.kicad_pcb, PD-AuxPower-Card.kicad_sch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]
2023-07-22 Initial commit. Add source file of PCB and Firmware, the firmware not support any communication yet, but only can show LED effect for its alive.
    [12V_Isolate.kicad_sch, PD-AuxPower-Card.kicad_pcb, PD-AuxPower-Card.kicad_sch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]
2023-07-29 FEAT: Add house keeping timer (tim16 )for checking switches status. Add I2C test function asking FUSB302B some data.
    [PD-AuxPower-Card.kicad_sch]
2023-08-03 FEAT: Add ADC sampling function for current/voltage sensing. Using timer16 ISR to trigger ADC DMA sampling request, and put the value into different variable for controller used.
2023-08-03 FEAT: Add UART communication showing 4 ADC read value and output voltage mode select status. baud rate = 115200, no parity bit, stop bit is set to 1.
2023-08-03 FEAT: Add PWM feature for MOSFET driven
2023-08-11 FEAT: Change PWM frequency to 50kHz, fix LED indicator bug PCB FIX: Adjust ophotocoupler feedback resistor value
    [12V_Isolate.kicad_sch, Power_Stage.kicad_sch]
2023-08-12 FEAT: Add PID algorithm for output voltage control. NOT TUNE YET! Change ADC1 trigger source into TIM1 TRGO for update event. Synchronised TIM2 and TIM1 by using slave mode. PCB: Change TL431 to TLV4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
    [12V_Isolate.kicad_sch, PD-AuxPower-Card.kicad_pcb, Power_Stage.kicad_sch]
2023-08-13 PCB: Update LTV-214 footprint and update to PCB layout.
    [12V_Isolate.kicad_sch, PD-AuxPower-Card.kicad_pcb, Power_Stage.kicad_sch]
2023-08-24 FEAT: Increase PWM frequency to 200kHz, add PD protocol lib prototype. PCB: Add comment of 12/24V feedback loop. Doc: Change technical reference manual for STM32L4xx
    [12V_Isolate.kicad_sch]
2023-09-29 FEAT: Set I2C mode to standard mode(100kHz), change FUSB302B driver header file definition, trimming output voltage of 3.3/5V channel and 12/24V channel by optocoupler current reduce to 1mA. Add rese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
    [12V_Isolate.kicad_sch, Power_Stage.kicad_sch]
2023-09-29 FEAT: Add CC pin detect feature for CC communication switch setup.
2023-10-01 FEAT: Disable PD logic reset
    [FUSB302B_driver.c]
2023-12-07 FEAT: Revolution PCB to ver 1.0. Change COMP1+ to 3v3 current sense, COMP2+ to 12V current sense and 12V LED to GPIO7 output. Modify PCB layout.
    [12V_Isolate.kicad_sch, PD-AuxPower-Card.kicad_pcb, PD-AuxPower-Card.kicad_sch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]
2023-12-28 HW: FEAT: Relayout circuit and some adjustment. FW: Change .ico file to match schematic, add COMP for current limiting
    [PD-AuxPower-Card.kicad_sch]
2024-02-14 FEAT: Add Matlab file (Octave capable) for calculation transformer parameter. Modify PCB schematic Redefine pinout, ISR and peripherial
    [PD-AuxPower-Card.kicad_sch, Power_Stage.kicad_sch]

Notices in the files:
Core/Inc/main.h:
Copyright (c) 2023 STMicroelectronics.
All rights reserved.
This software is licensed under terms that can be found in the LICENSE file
